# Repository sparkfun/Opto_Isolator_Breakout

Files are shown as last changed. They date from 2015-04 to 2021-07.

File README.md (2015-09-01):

SparkFun Opto-isolator Breakout 
===============================

SparkFun Opto-isolator Breakout

[*SparkFun Opto-isolator Breakout  (BOB-09118)*](https://www.sparkfun.com/products/9118)

This is a board designed for opto-isolation. 
This board is helpful for connecting digital systems (like a 5V microcontroller) to a high-voltage or noisy system. 
This board electrically isolates a controller from the high-power system by use of an opto-isolator IC.

Repository Contents
-------------------

* **/Hardware** - Eagle design files (.brd, .sch)
* **/Production** - Production panel files (.brd)

Documentation
--------------
* **[SparkFun Fritzing repo](https://github.com/sparkfun/Fritzing_Parts)** - Fritzing diagrams for SparkFun products.
* **[SparkFun 3D Model repo](https://github.com/sparkfun/3D_Models)** - 3D models of SparkFun products. 

License Information
-------------------

This product is _**open source**_! 

Please review the LICENSE.md file for license information. 

If you have any questions or concerns on licensing, please contact techsupport@sparkfun.com.

Distributed as-is; no warranty is given.

- Your friends at SparkFun.

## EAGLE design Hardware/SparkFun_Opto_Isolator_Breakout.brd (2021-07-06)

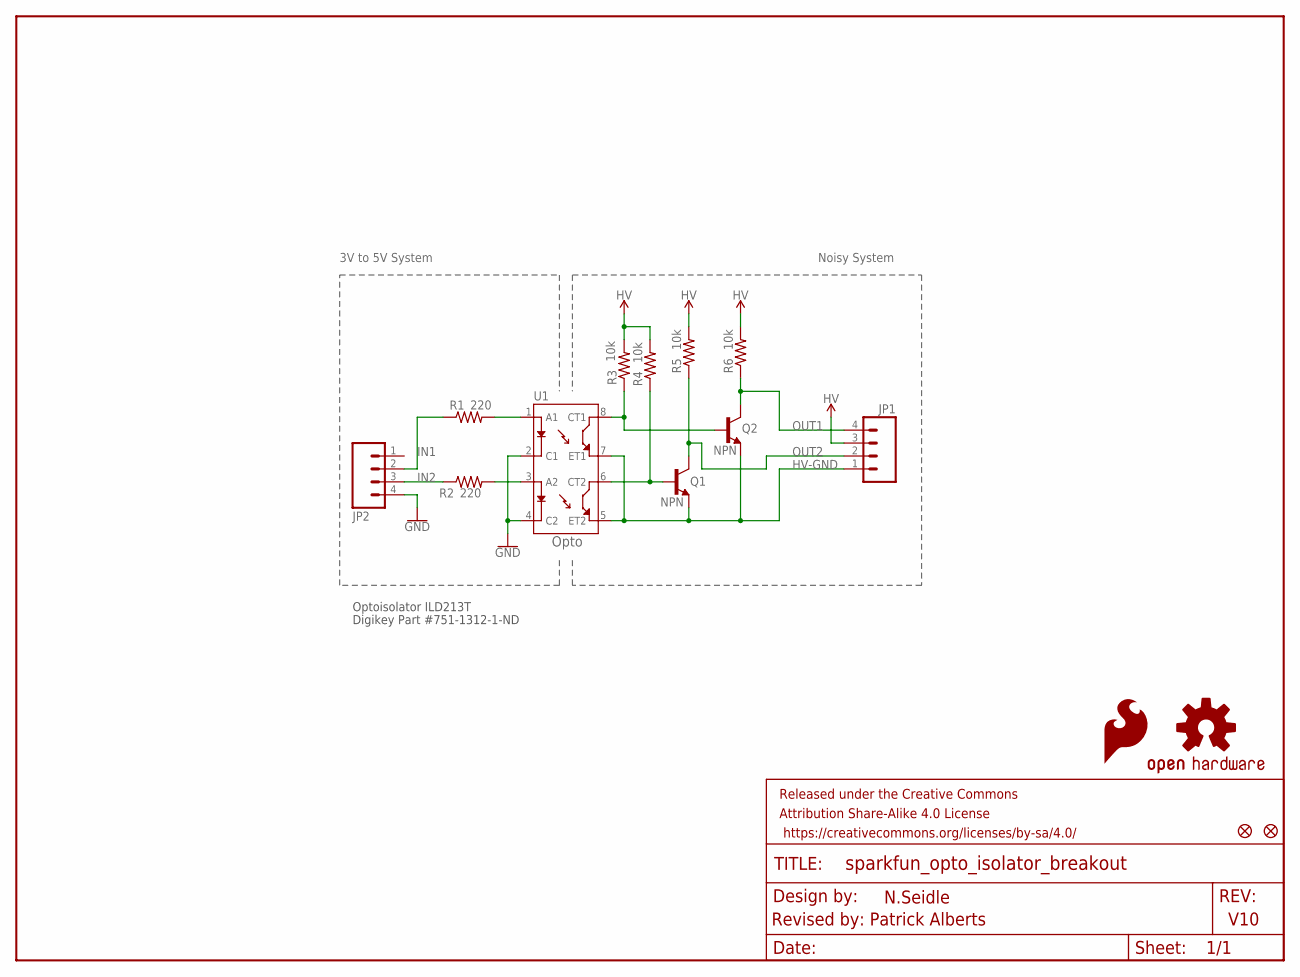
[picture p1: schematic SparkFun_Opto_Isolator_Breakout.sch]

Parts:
FRAME1: FRAME-LETTER; CREATIVE_COMMONS
JP1, JP2: M04PTH; 1X04
LOGO1: OSHW-LOGOS; OSHW-LOGO-S
LOGO2: SFE_LOGO_FLAME.1_INCH; SFE_LOGO_FLAME_.1
Q1, Q2: NPN; SOT23-3
R1, R2: 220; 0603
R3, R4, R5, R6: 10k; 0603
U1: ILD213T-IDL213T; SO08
U$2, U$3: FIDUCIALUFIDUCIAL; MICRO-FIDUCIAL

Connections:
GND: JP2.4, U1.2 (C1), U1.4 (C2)
HV-GND: JP1.1, Q1.2 (E), Q2.2 (E), U1.5 (ET2), U1.7 (ET1)
IN1: JP2.2, R1.1
IN2: JP2.3, R2.1
unnamed: R1.2, U1.1 (A1)
unnamed: R2.2, U1.3 (A2)
OUT1: JP1.4, Q2.3 (C), R6.1
OUT1N: Q2.1 (B), R3.1, U1.8 (CT1)
OUT2: JP1.2, Q1.3 (C), R5.1
OUT2N: Q1.1 (B), R4.1, U1.6 (CT2)
VCC: JP1.3, R3.2, R4.2, R5.2, R6.2

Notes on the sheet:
Optoisolator ILD213T
Digikey Part #751-1312-1-ND
3V to 5V System
Noisy System
V10
Revised by: Patrick Alberts
N.Seidle
Opto

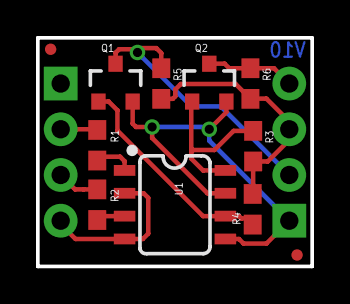
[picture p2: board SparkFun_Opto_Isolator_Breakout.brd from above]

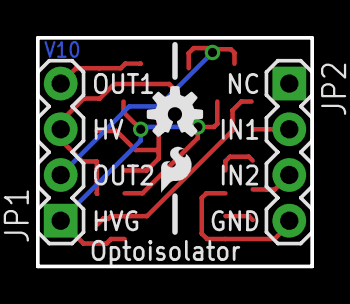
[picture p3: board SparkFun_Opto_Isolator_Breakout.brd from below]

Board: 2 copper layers, 15.2 x 12.7 mm, 16 parts (4 on the bottom side), 11 nets.

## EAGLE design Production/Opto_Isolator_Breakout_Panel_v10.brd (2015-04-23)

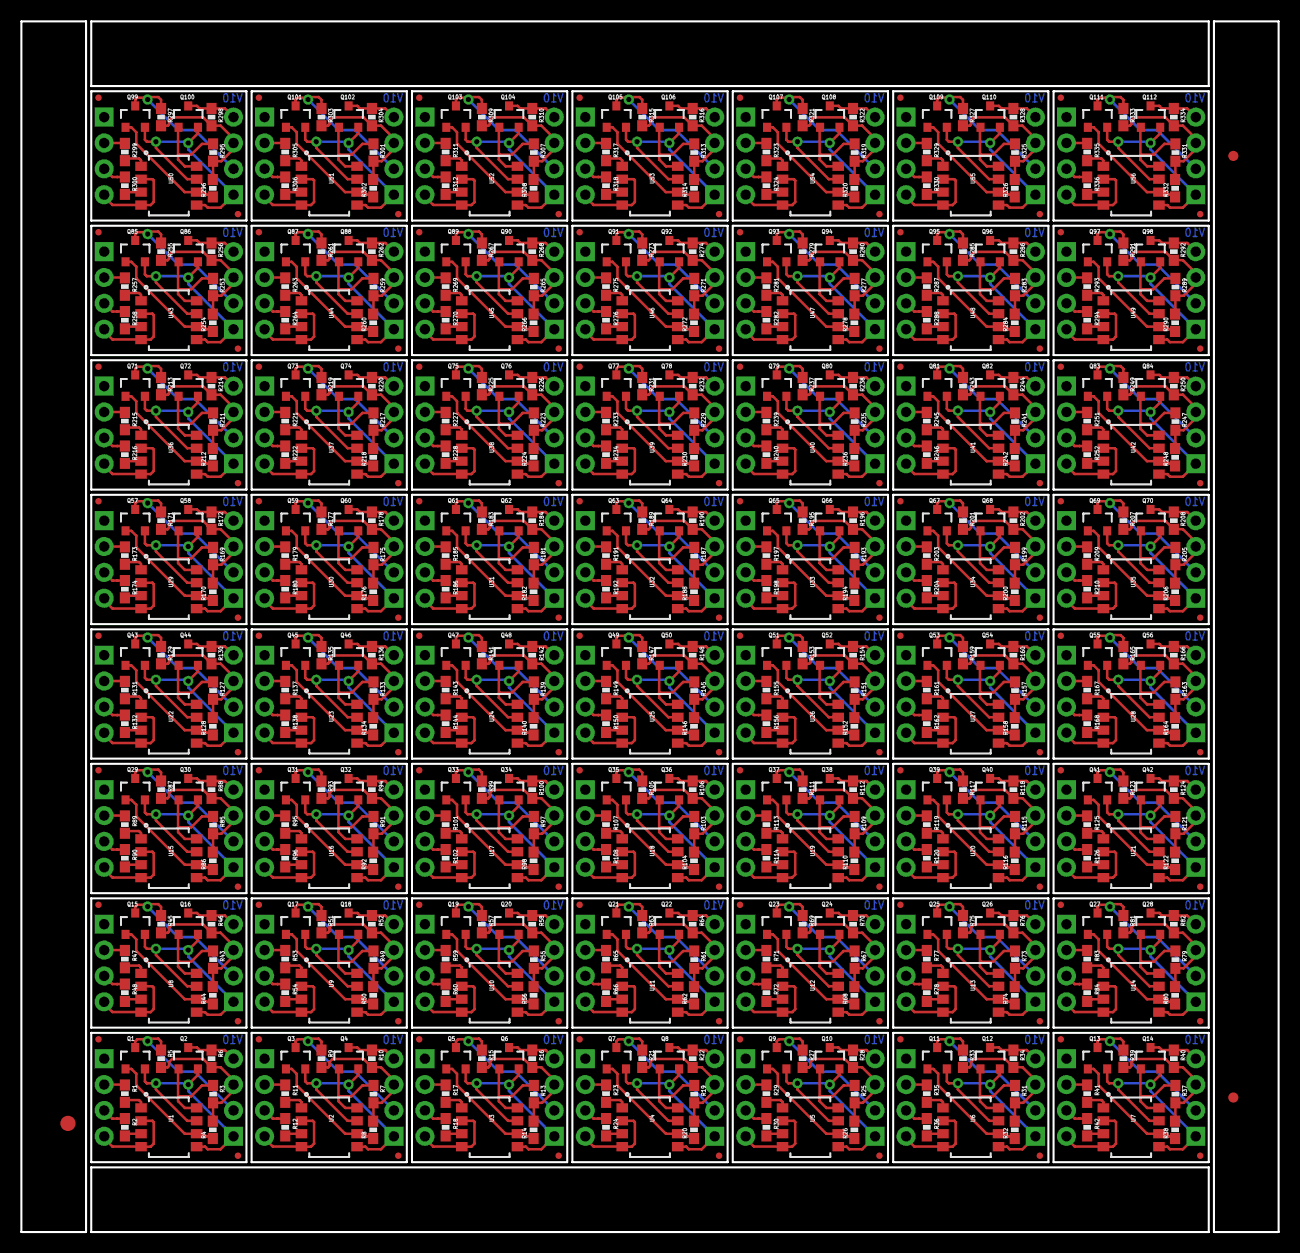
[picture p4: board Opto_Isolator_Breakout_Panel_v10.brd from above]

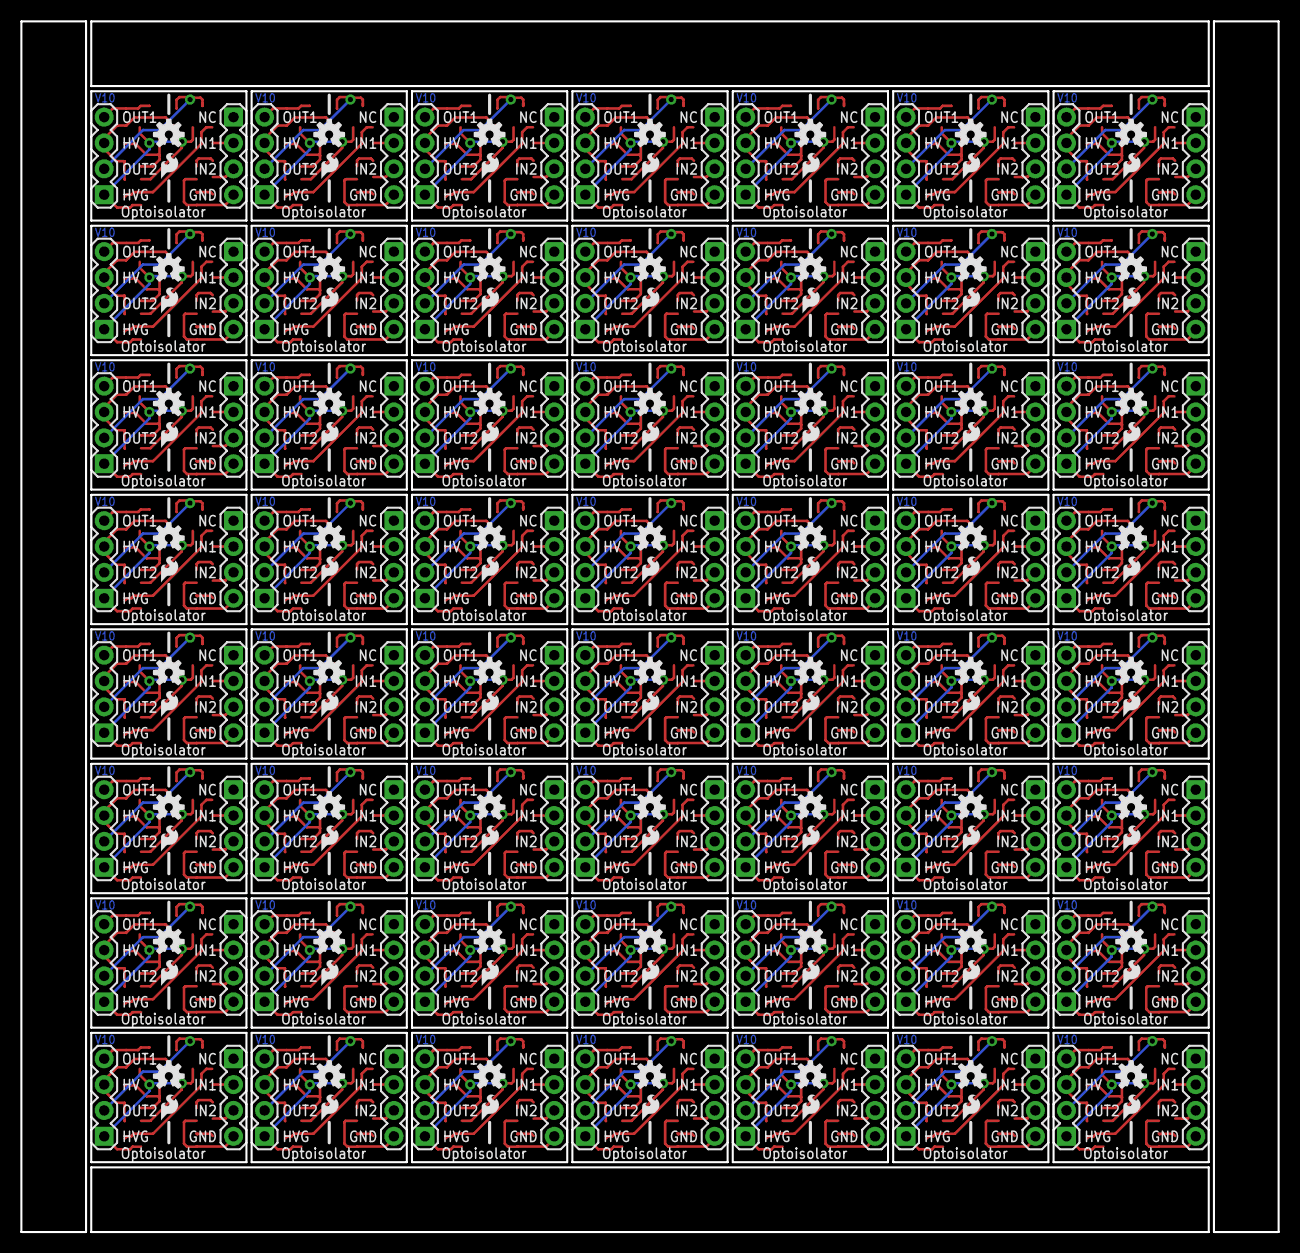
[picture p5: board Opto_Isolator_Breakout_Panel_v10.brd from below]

Board: 2 copper layers, 123.4 x 118.9 mm, 843 parts (224 on the bottom side), 616 nets.

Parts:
E$1: FIDUCIAL-1.5X3
E$4, E$5: FIDUCIAL-1X2
JP1, JP2, JP3, JP4, JP5, JP6, JP7, JP8, JP9, JP10, JP11, JP12, JP13, JP14, JP15, JP16, JP17, JP18, JP19, JP20, JP21, JP22, JP23, JP24, JP25, JP26, JP27, JP28, JP29, JP30, JP31, JP32, JP33, JP34, JP35, JP36, JP37, JP38, JP39, JP40, JP41, JP42, JP43, JP44, JP45, JP46, JP47, JP48, JP49, JP50, JP51, JP52, JP53, JP54, JP55, JP56, JP57, JP58, JP59, JP60, JP61, JP62, JP63, JP64, JP65, JP66, JP67, JP68, JP69, JP70, JP71, JP72, JP73, JP74, JP75, JP76, JP77, JP78, JP79, JP80, JP81, JP82, JP83, JP84, JP85, JP86, JP87, JP88, JP89, JP90, JP91, JP92, JP93, JP94, JP95, JP96, JP97, JP98, JP99, JP100, JP101, JP102, JP103, JP104, JP105, JP106, JP107, JP108, JP109, JP110, JP111, JP112: 1X04
LOGO1, LOGO4, LOGO6, LOGO8, LOGO10, LOGO12, LOGO14, LOGO16, LOGO18, LOGO20, LOGO22, LOGO24, LOGO26, LOGO28, LOGO30, LOGO32, LOGO34, LOGO36, LOGO38, LOGO40, LOGO42, LOGO44, LOGO46, LOGO48, LOGO50, LOGO52, LOGO54, LOGO56, LOGO58, LOGO60, LOGO62, LOGO64, LOGO66, LOGO68, LOGO70, LOGO72, LOGO74, LOGO76, LOGO78, LOGO80, LOGO82, LOGO84, LOGO86, LOGO88, LOGO90, LOGO92, LOGO94, LOGO96, LOGO98, LOGO100, LOGO102, LOGO104, LOGO106, LOGO108, LOGO110, LOGO112: OSHW-LOGOS; OSHW-LOGO-S
LOGO2, LOGO3, LOGO5, LOGO7, LOGO9, LOGO11, LOGO13, LOGO15, LOGO17, LOGO19, LOGO21, LOGO23, LOGO25, LOGO27, LOGO29, LOGO31, LOGO33, LOGO35, LOGO37, LOGO39, LOGO41, LOGO43, LOGO45, LOGO47, LOGO49, LOGO51, LOGO53, LOGO55, LOGO57, LOGO59, LOGO61, LOGO63, LOGO65, LOGO67, LOGO69, LOGO71, LOGO73, LOGO75, LOGO77, LOGO79, LOGO81, LOGO83, LOGO85, LOGO87, LOGO89, LOGO91, LOGO93, LOGO95, LOGO97, LOGO99, LOGO101, LOGO103, LOGO105, LOGO107, LOGO109, LOGO111: SFE_LOGO_FLAME.1_INCH; SFE_LOGO_FLAME_.1
Q1, Q2, Q3, Q4, Q5, Q6, Q7, Q8, Q9, Q10, Q11, Q12, Q13, Q14, Q15, Q16, Q17, Q18, Q19, Q20, Q21, Q22, Q23, Q24, Q25, Q26, Q27, Q28, Q29, Q30, Q31, Q32, Q33, Q34, Q35, Q36, Q37, Q38, Q39, Q40, Q41, Q42, Q43, Q44, Q45, Q46, Q47, Q48, Q49, Q50, Q51, Q52, Q53, Q54, Q55, Q56, Q57, Q58, Q59, Q60, Q61, Q62, Q63, Q64, Q65, Q66, Q67, Q68, Q69, Q70, Q71, Q72, Q73, Q74, Q75, Q76, Q77, Q78, Q79, Q80, Q81, Q82, Q83, Q84, Q85, Q86, Q87, Q88, Q89, Q90, Q91, Q92, Q93, Q94, Q95, Q96, Q97, Q98, Q99, Q100, Q101, Q102, Q103, Q104, Q105, Q106, Q107, Q108, Q109, Q110, Q111, Q112: NPN; SOT23-3
R1, R2, R11, R12, R17, R18, R23, R24, R29, R30, R35, R36, R41, R42, R47, R48, R53, R54, R59, R60, R65, R66, R71, R72, R77, R78, R83, R84, R89, R90, R95, R96, R101, R102, R107, R108, R113, R114, R119, R120, R125, R126, R131, R132, R137, R138, R143, R144, R149, R150, R155, R156, R161, R162, R167, R168, R173, R174, R179, R180, R185, R186, R191, R192, R197, R198, R203, R204, R209, R210, R215, R216, R221, R222, R227, R228, R233, R234, R239, R240, R245, R246, R251, R252, R257, R258, R263, R264, R269, R270, R275, R276, R281, R282, R287, R288, R293, R294, R299, R300, R305, R306, R311, R312, R317, R318, R323, R324, R329, R330, R335, R336: 220; 0603-RES
R3, R4, R5, R6, R7, R8, R9, R10, R13, R14, R15, R16, R19, R20, R21, R22, R25, R26, R27, R28, R31, R32, R33, R34, R37, R38, R39, R40, R43, R44, R45, R46, R49, R50, R51, R52, R55, R56, R57, R58, R61, R62, R63, R64, R67, R68, R69, R70, R73, R74, R75, R76, R79, R80, R81, R82, R85, R86, R87, R88, R91, R92, R93, R94, R97, R98, R99, R100, R103, R104, R105, R106, R109, R110, R111, R112, R115, R116, R117, R118, R121, R122, R123, R124, R127, R128, R129, R130, R133, R134, R135, R136, R139, R140, R141, R142, R145, R146, R147, R148, R151, R152, R153, R154, R157, R158, R159, R160, R163, R164, R165, R166, R169, R170, R171, R172, R175, R176, R177, R178, R181, R182, R183, R184, R187, R188, R189, R190, R193, R194, R195, R196, R199, R200, R201, R202, R205, R206, R207, R208, R211, R212, R213, R214, R217, R218, R219, R220, R223, R224, R225, R226, R229, R230, R231, R232, R235, R236, R237, R238, R241, R242, R243, R244, R247, R248, R249, R250, R253, R254, R255, R256, R259, R260, R261, R262, R265, R266, R267, R268, R271, R272, R273, R274, R277, R278, R279, R280, R283, R284, R285, R286, R289, R290, R291, R292, R295, R296, R297, R298, R301, R302, R303, R304, R307, R308, R309, R310, R313, R314, R315, R316, R319, R320, R321, R322, R325, R326, R327, R328, R331, R332, R333, R334: 10K; 0603-RES
U1, U2, U3, U4, U5, U6, U7, U8, U9, U10, U11, U12, U13, U14, U15, U16, U17, U18, U19, U20, U21, U22, U23, U24, U25, U26, U27, U28, U29, U30, U31, U32, U33, U34, U35, U36, U37, U38, U39, U40, U41, U42, U43, U44, U45, U46, U47, U48, U49, U50, U51, U52, U53, U54, U55, U56: OPTOISOLATOR-2SOIC8; SO08-2
U$1, U$2, U$3, U$4, U$5, U$6, U$7, U$8, U$9, U$10, U$11, U$12, U$13, U$14, U$15, U$16, U$17, U$18, U$19, U$20, U$21, U$22, U$23, U$24, U$25, U$26, U$27, U$28, U$29, U$30, U$31, U$32, U$33, U$34, U$35, U$36, U$37, U$38, U$39, U$40, U$41, U$42, U$43, U$44, U$45, U$46, U$47, U$48, U$49, U$50, U$51, U$52, U$53, U$54, U$55, U$56, U$57, U$58, U$59, U$60, U$61, U$62, U$63, U$64, U$65, U$66, U$67, U$68, U$69, U$70, U$71, U$72, U$73, U$74, U$75, U$76, U$77, U$78, U$79, U$80, U$81, U$82, U$83, U$84, U$85, U$86, U$87, U$88, U$89, U$90, U$91, U$92, U$93, U$94, U$95, U$96, U$97, U$98, U$99, U$100, U$101, U$102, U$103, U$104, U$105, U$106, U$107, U$108, U$109, U$110, U$111, U$112: FIDUCIALUFIDUCIAL; MICRO-FIDUCIAL

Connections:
GND: JP2.4, U1.2, U1.4
GND1: JP4.4, U2.2, U2.4
GND2: JP6.4, U3.2, U3.4
GND3: JP8.4, U4.2, U4.4
GND4: JP10.4, U5.2, U5.4
GND5: JP12.4, U6.2, U6.4
GND6: JP14.4, U7.2, U7.4
GND7: JP16.4, U8.2, U8.4
GND8: JP18.4, U9.2, U9.4
GND9: JP20.4, U10.2, U10.4
GND10: JP22.4, U11.2, U11.4
GND11: JP24.4, U12.2, U12.4
GND12: JP26.4, U13.2, U13.4
GND13: JP28.4, U14.2, U14.4
GND14: JP30.4, U15.2, U15.4
GND15: JP32.4, U16.2, U16.4
GND16: JP34.4, U17.2, U17.4
GND17: JP36.4, U18.2, U18.4
GND18: JP38.4, U19.2, U19.4
GND19: JP40.4, U20.2, U20.4
GND20: JP42.4, U21.2, U21.4
GND21: JP44.4, U22.2, U22.4
GND22: JP46.4, U23.2, U23.4
GND23: JP48.4, U24.2, U24.4
GND24: JP50.4, U25.2, U25.4
GND25: JP52.4, U26.2, U26.4
GND26: JP54.4, U27.2, U27.4
GND27: JP56.4, U28.2, U28.4
GND28: JP58.4, U29.2, U29.4
GND29: JP60.4, U30.2, U30.4
GND30: JP62.4, U31.2, U31.4
GND31: JP64.4, U32.2, U32.4
GND32: JP66.4, U33.2, U33.4
GND33: JP68.4, U34.2, U34.4
GND34: JP70.4, U35.2, U35.4
GND35: JP72.4, U36.2, U36.4
GND36: JP74.4, U37.2, U37.4
GND37: JP76.4, U38.2, U38.4
GND38: JP78.4, U39.2, U39.4
GND39: JP80.4, U40.2, U40.4
GND40: JP82.4, U41.2, U41.4
GND41: JP84.4, U42.2, U42.4
GND42: JP86.4, U43.2, U43.4
GND43: JP88.4, U44.2, U44.4
GND44: JP90.4, U45.2, U45.4
GND45: JP92.4, U46.2, U46.4
GND46: JP94.4, U47.2, U47.4
GND47: JP96.4, U48.2, U48.4
GND48: JP98.4, U49.2, U49.4
GND49: JP100.4, U50.2, U50.4
GND50: JP102.4, U51.2, U51.4
GND51: JP104.4, U52.2, U52.4
GND52: JP106.4, U53.2, U53.4
GND53: JP108.4, U54.2, U54.4
GND54: JP110.4, U55.2, U55.4
GND55: JP112.4, U56.2, U56.4
HV-GND: JP1.1, Q1.2, Q2.2, U1.5, U1.7
HV-GND1: JP3.1, Q3.2, Q4.2, U2.5, U2.7
HV-GND2: JP5.1, Q5.2, Q6.2, U3.5, U3.7
HV-GND3: JP7.1, Q7.2, Q8.2, U4.5, U4.7
HV-GND4: JP9.1, Q9.2, Q10.2, U5.5, U5.7
HV-GND5: JP11.1, Q11.2, Q12.2, U6.5, U6.7
HV-GND6: JP13.1, Q13.2, Q14.2, U7.5, U7.7
HV-GND7: JP15.1, Q15.2, Q16.2, U8.5, U8.7
HV-GND8: JP17.1, Q17.2, Q18.2, U9.5, U9.7
HV-GND9: JP19.1, Q19.2, Q20.2, U10.5, U10.7
HV-GND10: JP21.1, Q21.2, Q22.2, U11.5, U11.7
HV-GND11: JP23.1, Q23.2, Q24.2, U12.5, U12.7
HV-GND12: JP25.1, Q25.2, Q26.2, U13.5, U13.7
HV-GND13: JP27.1, Q27.2, Q28.2, U14.5, U14.7
HV-GND14: JP29.1, Q29.2, Q30.2, U15.5, U15.7
HV-GND15: JP31.1, Q31.2, Q32.2, U16.5, U16.7
HV-GND16: JP33.1, Q33.2, Q34.2, U17.5, U17.7
HV-GND17: JP35.1, Q35.2, Q36.2, U18.5, U18.7
HV-GND18: JP37.1, Q37.2, Q38.2, U19.5, U19.7
HV-GND19: JP39.1, Q39.2, Q40.2, U20.5, U20.7
HV-GND20: JP41.1, Q41.2, Q42.2, U21.5, U21.7
HV-GND21: JP43.1, Q43.2, Q44.2, U22.5, U22.7
HV-GND22: JP45.1, Q45.2, Q46.2, U23.5, U23.7
HV-GND23: JP47.1, Q47.2, Q48.2, U24.5, U24.7
HV-GND24: JP49.1, Q49.2, Q50.2, U25.5, U25.7
HV-GND25: JP51.1, Q51.2, Q52.2, U26.5, U26.7
HV-GND26: JP53.1, Q53.2, Q54.2, U27.5, U27.7
HV-GND27: JP55.1, Q55.2, Q56.2, U28.5, U28.7
HV-GND28: JP57.1, Q57.2, Q58.2, U29.5, U29.7
HV-GND29: JP59.1, Q59.2, Q60.2, U30.5, U30.7
HV-GND30: JP61.1, Q61.2, Q62.2, U31.5, U31.7
HV-GND31: JP63.1, Q63.2, Q64.2, U32.5, U32.7
HV-GND32: JP65.1, Q65.2, Q66.2, U33.5, U33.7
HV-GND33: JP67.1, Q67.2, Q68.2, U34.5, U34.7
HV-GND34: JP69.1, Q69.2, Q70.2, U35.5, U35.7
HV-GND35: JP71.1, Q71.2, Q72.2, U36.5, U36.7
HV-GND36: JP73.1, Q73.2, Q74.2, U37.5, U37.7
HV-GND37: JP75.1, Q75.2, Q76.2, U38.5, U38.7
HV-GND38: JP77.1, Q77.2, Q78.2, U39.5, U39.7
HV-GND39: JP79.1, Q79.2, Q80.2, U40.5, U40.7
HV-GND40: JP81.1, Q81.2, Q82.2, U41.5, U41.7
HV-GND41: JP83.1, Q83.2, Q84.2, U42.5, U42.7
HV-GND42: JP85.1, Q85.2, Q86.2, U43.5, U43.7
HV-GND43: JP87.1, Q87.2, Q88.2, U44.5, U44.7
HV-GND44: JP89.1, Q89.2, Q90.2, U45.5, U45.7
HV-GND45: JP91.1, Q91.2, Q92.2, U46.5, U46.7
HV-GND46: JP93.1, Q93.2, Q94.2, U47.5, U47.7
HV-GND47: JP95.1, Q95.2, Q96.2, U48.5, U48.7
HV-GND48: JP97.1, Q97.2, Q98.2, U49.5, U49.7
HV-GND49: JP99.1, Q99.2, Q100.2, U50.5, U50.7
HV-GND50: JP101.1, Q101.2, Q102.2, U51.5, U51.7
HV-GND51: JP103.1, Q103.2, Q104.2, U52.5, U52.7
HV-GND52: JP105.1, Q105.2, Q106.2, U53.5, U53.7
HV-GND53: JP107.1, Q107.2, Q108.2, U54.5, U54.7
HV-GND54: JP109.1, Q109.2, Q110.2, U55.5, U55.7
HV-GND55: JP111.1, Q111.2, Q112.2, U56.5, U56.7
IN1: JP2.2, R1.1
IN2: JP2.3, R2.1
IN3: JP4.3, R12.1
IN4: JP4.2, R11.1
IN5: JP6.3, R18.1
IN6: JP6.2, R17.1
IN7: JP8.3, R24.1
IN8: JP8.2, R23.1
IN9: JP10.3, R30.1
IN10: JP10.2, R29.1
IN11: JP12.3, R36.1
IN12: JP12.2, R35.1
IN13: JP14.3, R42.1
IN14: JP14.2, R41.1
IN15: JP16.3, R48.1
IN16: JP16.2, R47.1
IN17: JP18.3, R54.1
IN18: JP18.2, R53.1
IN19: JP20.3, R60.1
IN20: JP20.2, R59.1
IN21: JP22.3, R66.1
IN22: JP22.2, R65.1
IN23: JP24.3, R72.1
IN24: JP24.2, R71.1
IN25: JP26.3, R78.1
IN26: JP26.2, R77.1
IN27: JP28.3, R84.1
IN28: JP28.2, R83.1
IN29: JP30.3, R90.1
IN30: JP30.2, R89.1
IN31: JP32.3, R96.1
IN32: JP32.2, R95.1
IN33: JP34.3, R102.1
IN34: JP34.2, R101.1
IN35: JP36.3, R108.1
IN36: JP36.2, R107.1
IN37: JP38.3, R114.1
IN38: JP38.2, R113.1
IN39: JP40.3, R120.1
IN40: JP40.2, R119.1
IN41: JP42.3, R126.1
IN42: JP42.2, R125.1
IN43: JP44.3, R132.1
IN44: JP44.2, R131.1
IN45: JP46.3, R138.1
IN46: JP46.2, R137.1
IN47: JP48.3, R144.1
IN48: JP48.2, R143.1
IN49: JP50.3, R150.1
IN50: JP50.2, R149.1
IN51: JP52.3, R156.1
IN52: JP52.2, R155.1
IN53: JP54.3, R162.1
IN54: JP54.2, R161.1
IN55: JP56.3, R168.1
IN56: JP56.2, R167.1
IN57: JP58.3, R174.1
IN58: JP58.2, R173.1
IN59: JP60.3, R180.1
IN60: JP60.2, R179.1
IN61: JP62.3, R186.1
IN62: JP62.2, R185.1
IN63: JP64.3, R192.1
IN64: JP64.2, R191.1
IN65: JP66.3, R198.1
IN66: JP66.2, R197.1
IN67: JP68.3, R204.1
IN68: JP68.2, R203.1
IN69: JP70.3, R210.1
IN70: JP70.2, R209.1
IN71: JP72.3, R216.1
IN72: JP72.2, R215.1
IN73: JP74.3, R222.1
IN74: JP74.2, R221.1
IN75: JP76.3, R228.1
IN76: JP76.2, R227.1
IN77: JP78.3, R234.1
IN78: JP78.2, R233.1
IN79: JP80.3, R240.1
IN80: JP80.2, R239.1
IN81: JP82.3, R246.1
IN82: JP82.2, R245.1
IN83: JP84.3, R252.1
IN84: JP84.2, R251.1
IN85: JP86.3, R258.1
IN86: JP86.2, R257.1
IN87: JP88.3, R264.1
IN88: JP88.2, R263.1
IN89: JP90.3, R270.1
IN90: JP90.2, R269.1
IN91: JP92.3, R276.1
IN92: JP92.2, R275.1
IN93: JP94.3, R282.1
IN94: JP94.2, R281.1
IN95: JP96.3, R288.1
IN96: JP96.2, R287.1
IN97: JP98.3, R294.1
IN98: JP98.2, R293.1
IN99: JP100.3, R300.1
IN100: JP100.2, R299.1
IN101: JP102.3, R306.1
IN102: JP102.2, R305.1
IN103: JP104.3, R312.1
IN104: JP104.2, R311.1
IN105: JP106.3, R318.1
IN106: JP106.2, R317.1
IN107: JP108.3, R324.1
IN108: JP108.2, R323.1
IN109: JP110.3, R330.1
IN110: JP110.2, R329.1
IN111: JP112.3, R336.1
IN112: JP112.2, R335.1
unnamed: R1.2, U1.1
unnamed: R2.2, U1.3
unnamed: R11.2, U2.1
unnamed: R12.2, U2.3
unnamed: R17.2, U3.1
unnamed: R18.2, U3.3
unnamed: R23.2, U4.1
unnamed: R24.2, U4.3
unnamed: R29.2, U5.1
unnamed: R30.2, U5.3
unnamed: R35.2, U6.1
unnamed: R36.2, U6.3
unnamed: R41.2, U7.1
unnamed: R42.2, U7.3
unnamed: R47.2, U8.1
unnamed: R48.2, U8.3
unnamed: R53.2, U9.1
unnamed: R54.2, U9.3
unnamed: R59.2, U10.1
unnamed: R60.2, U10.3
unnamed: R65.2, U11.1
unnamed: R66.2, U11.3
unnamed: R71.2, U12.1
unnamed: R72.2, U12.3
unnamed: R77.2, U13.1
unnamed: R78.2, U13.3
unnamed: R83.2, U14.1
unnamed: R84.2, U14.3
unnamed: R89.2, U15.1
unnamed: R90.2, U15.3
unnamed: R95.2, U16.1
unnamed: R96.2, U16.3
unnamed: R101.2, U17.1
unnamed: R102.2, U17.3
unnamed: R107.2, U18.1
unnamed: R108.2, U18.3
unnamed: R113.2, U19.1
unnamed: R114.2, U19.3
unnamed: R119.2, U20.1
unnamed: R120.2, U20.3
unnamed: R125.2, U21.1
unnamed: R126.2, U21.3
unnamed: R131.2, U22.1
unnamed: R132.2, U22.3
unnamed: R137.2, U23.1
unnamed: R138.2, U23.3
unnamed: R143.2, U24.1
unnamed: R144.2, U24.3
unnamed: R149.2, U25.1
unnamed: R150.2, U25.3
unnamed: R155.2, U26.1
unnamed: R156.2, U26.3
unnamed: R161.2, U27.1
unnamed: R162.2, U27.3
unnamed: R167.2, U28.1
unnamed: R168.2, U28.3
unnamed: R173.2, U29.1
unnamed: R174.2, U29.3
unnamed: R179.2, U30.1
unnamed: R180.2, U30.3
unnamed: R185.2, U31.1
unnamed: R186.2, U31.3
unnamed: R191.2, U32.1
unnamed: R192.2, U32.3
unnamed: R197.2, U33.1
unnamed: R198.2, U33.3
unnamed: R203.2, U34.1
unnamed: R204.2, U34.3
unnamed: R209.2, U35.1
unnamed: R210.2, U35.3
unnamed: R215.2, U36.1
unnamed: R216.2, U36.3
unnamed: R221.2, U37.1
unnamed: R222.2, U37.3
unnamed: R227.2, U38.1
unnamed: R228.2, U38.3
unnamed: R233.2, U39.1
unnamed: R234.2, U39.3
unnamed: R239.2, U40.1
unnamed: R240.2, U40.3
unnamed: R245.2, U41.1
unnamed: R246.2, U41.3
unnamed: R251.2, U42.1
unnamed: R252.2, U42.3
unnamed: R257.2, U43.1
unnamed: R258.2, U43.3
unnamed: R263.2, U44.1
unnamed: R264.2, U44.3
unnamed: R269.2, U45.1
unnamed: R270.2, U45.3
unnamed: R275.2, U46.1
unnamed: R276.2, U46.3
unnamed: R281.2, U47.1
unnamed: R282.2, U47.3
unnamed: R287.2, U48.1
unnamed: R288.2, U48.3
unnamed: R293.2, U49.1
unnamed: R294.2, U49.3
unnamed: R299.2, U50.1
unnamed: R300.2, U50.3
unnamed: R305.2, U51.1
unnamed: R306.2, U51.3
unnamed: R311.2, U52.1
unnamed: R312.2, U52.3
unnamed: R317.2, U53.1
unnamed: R318.2, U53.3
unnamed: R323.2, U54.1
unnamed: R324.2, U54.3
unnamed: R329.2, U55.1
unnamed: R330.2, U55.3
unnamed: R335.2, U56.1
unnamed: R336.2, U56.3
OUT1: JP1.4, Q2.3, R6.1
OUT1N: Q2.1, R3.1, U1.8
OUT1N1: Q4.1, R7.1, U2.8
OUT1N2: Q6.1, R13.1, U3.8
OUT1N3: Q8.1, R19.1, U4.8
OUT1N4: Q10.1, R25.1, U5.8
OUT1N5: Q12.1, R31.1, U6.8
OUT1N6: Q14.1, R37.1, U7.8
OUT1N7: Q16.1, R43.1, U8.8
OUT1N8: Q18.1, R49.1, U9.8
OUT1N9: Q20.1, R55.1, U10.8
OUT1N10: Q22.1, R61.1, U11.8
OUT1N11: Q24.1, R67.1, U12.8
OUT1N12: Q26.1, R73.1, U13.8
OUT1N13: Q28.1, R79.1, U14.8
OUT1N14: Q30.1, R85.1, U15.8
OUT1N15: Q32.1, R91.1, U16.8
OUT1N16: Q34.1, R97.1, U17.8
OUT1N17: Q36.1, R103.1, U18.8
OUT1N18: Q38.1, R109.1, U19.8
OUT1N19: Q40.1, R115.1, U20.8
OUT1N20: Q42.1, R121.1, U21.8
OUT1N21: Q44.1, R127.1, U22.8
OUT1N22: Q46.1, R133.1, U23.8
OUT1N23: Q48.1, R139.1, U24.8
OUT1N24: Q50.1, R145.1, U25.8
OUT1N25: Q52.1, R151.1, U26.8
OUT1N26: Q54.1, R157.1, U27.8
OUT1N27: Q56.1, R163.1, U28.8
OUT1N28: Q58.1, R169.1, U29.8
OUT1N29: Q60.1, R175.1, U30.8
OUT1N30: Q62.1, R181.1, U31.8
OUT1N31: Q64.1, R187.1, U32.8
OUT1N32: Q66.1, R193.1, U33.8
OUT1N33: Q68.1, R199.1, U34.8
OUT1N34: Q70.1, R205.1, U35.8
OUT1N35: Q72.1, R211.1, U36.8
OUT1N36: Q74.1, R217.1, U37.8
OUT1N37: Q76.1, R223.1, U38.8
OUT1N38: Q78.1, R229.1, U39.8
OUT1N39: Q80.1, R235.1, U40.8
OUT1N40: Q82.1, R241.1, U41.8
OUT1N41: Q84.1, R247.1, U42.8
OUT1N42: Q86.1, R253.1, U43.8
OUT1N43: Q88.1, R259.1, U44.8
OUT1N44: Q90.1, R265.1, U45.8
OUT1N45: Q92.1, R271.1, U46.8
OUT1N46: Q94.1, R277.1, U47.8
OUT1N47: Q96.1, R283.1, U48.8
OUT1N48: Q98.1, R289.1, U49.8
OUT1N49: Q100.1, R295.1, U50.8
OUT1N50: Q102.1, R301.1, U51.8
OUT1N51: Q104.1, R307.1, U52.8
OUT1N52: Q106.1, R313.1, U53.8
OUT1N53: Q108.1, R319.1, U54.8
OUT1N54: Q110.1, R325.1, U55.8
OUT1N55: Q112.1, R331.1, U56.8
OUT2: JP1.2, Q1.3, R5.1
OUT2N: Q1.1, R4.1, U1.6
OUT2N1: Q3.1, R8.1, U2.6
OUT2N2: Q5.1, R14.1, U3.6
OUT2N3: Q7.1, R20.1, U4.6
OUT2N4: Q9.1, R26.1, U5.6
OUT2N5: Q11.1, R32.1, U6.6
OUT2N6: Q13.1, R38.1, U7.6
OUT2N7: Q15.1, R44.1, U8.6
OUT2N8: Q17.1, R50.1, U9.6
OUT2N9: Q19.1, R56.1, U10.6
OUT2N10: Q21.1, R62.1, U11.6
OUT2N11: Q23.1, R68.1, U12.6
OUT2N12: Q25.1, R74.1, U13.6
OUT2N13: Q27.1, R80.1, U14.6
OUT2N14: Q29.1, R86.1, U15.6
OUT2N15: Q31.1, R92.1, U16.6
OUT2N16: Q33.1, R98.1, U17.6
OUT2N17: Q35.1, R104.1, U18.6
OUT2N18: Q37.1, R110.1, U19.6
OUT2N19: Q39.1, R116.1, U20.6
OUT2N20: Q41.1, R122.1, U21.6
OUT2N21: Q43.1, R128.1, U22.6
OUT2N22: Q45.1, R134.1, U23.6
OUT2N23: Q47.1, R140.1, U24.6
OUT2N24: Q49.1, R146.1, U25.6
OUT2N25: Q51.1, R152.1, U26.6
OUT2N26: Q53.1, R158.1, U27.6
OUT2N27: Q55.1, R164.1, U28.6
OUT2N28: Q57.1, R170.1, U29.6
OUT2N29: Q59.1, R176.1, U30.6
OUT2N30: Q61.1, R182.1, U31.6
OUT2N31: Q63.1, R188.1, U32.6
OUT2N32: Q65.1, R194.1, U33.6
OUT2N33: Q67.1, R200.1, U34.6
OUT2N34: Q69.1, R206.1, U35.6
OUT2N35: Q71.1, R212.1, U36.6
OUT2N36: Q73.1, R218.1, U37.6
OUT2N37: Q75.1, R224.1, U38.6
OUT2N38: Q77.1, R230.1, U39.6
OUT2N39: Q79.1, R236.1, U40.6
OUT2N40: Q81.1, R242.1, U41.6
OUT2N41: Q83.1, R248.1, U42.6
OUT2N42: Q85.1, R254.1, U43.6
OUT2N43: Q87.1, R260.1, U44.6
OUT2N44: Q89.1, R266.1, U45.6
OUT2N45: Q91.1, R272.1, U46.6
OUT2N46: Q93.1, R278.1, U47.6
OUT2N47: Q95.1, R284.1, U48.6
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

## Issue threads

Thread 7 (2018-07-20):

MIDI In issue

jardous, 2018-07-20:
Hello, I have bought this breakout board and wanted to use if for MIDI input for my Arduino based project. Unfortunately it seems to not be working.

A little googling pointed me to https://www.sparkfun.com/products/9118, where I found a review comment:

"The 10k load resistors on the “output side” mean the switching time of the optocoupled transistors are close to 100 us, which means baud rates above 9600 will not work. This means the breakout is useless for a MIDI application (which is optoisolated transmission at 31250 baud serial). So good for isolation, not for fast signalling."

I would expect that to be mentioned in the description. That could save some headache...

nseidle, 2018-07-23:
Agreed. Thanks for the feedback and sorry for the headache! Request for description is in. Should be changed shortly.

Closed 2018-07-23.

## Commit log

2014-10-29 initial commit with brd/sch
    [Opto_Isolator_Breakout.brd, Opto_Isolator_Breakout.sch]
2014-10-29 0603, sch changes, re routes, oshw and headers
    Update all res/caps to 0603
    minor trace re routes
    oshw added and sch frame update to letter
    moved feducials to micro
    updated headers to have correct annual ring size
    [Opto_Isolator_Breakout.brd, Opto_Isolator_Breakout.sch]
2014-11-06 Changed Res Values / SCH cleanup
    changed r1 and r2 to 200K
    Added version # and eng to board/sch files
    [Opto_Isolator_Breakout.brd, Opto_Isolator_Breakout.sch]
2015-01-14 Computer change
    [Opto_Isolator_Breakout.brd]
2015-03-26 Added attributes for IC IDL213T
    [Opto_Isolator_Breakout.brd, Opto_Isolator_Breakout.sch]
2015-03-31 Fixed qc checklist issues.
    [Opto_Isolator_Breakout.brd, Opto_Isolator_Breakout.sch]
2015-03-31 Fixed final qc checklist items.
    [Opto_Isolator_Breakout.brd, Opto_Isolator_Breakout.sch]
2015-04-20 Fixed QC checklist issues
    Fixed version # in sch and brd
    added "all units in inches" in layer 47
    [Opto_Isolator_Breakout.brd, Opto_Isolator_Breakout.sch]
2015-04-23 created panel v10
    [Opto_Isolator_Breakout_Panel_v10.brd]
2015-09-01 Adding license and .git files, updating README with product info
    [Opto_Isolator_Breakout_Panel_v10.brd, SparkFun_Opto_Isolator_Breakout.brd, SparkFun_Opto_Isolator_Breakout.sch]
2021-07-06 Replace ILD213T with updated part
    [SparkFun_Opto_Isolator_Breakout.brd, SparkFun_Opto_Isolator_Breakout.sch]

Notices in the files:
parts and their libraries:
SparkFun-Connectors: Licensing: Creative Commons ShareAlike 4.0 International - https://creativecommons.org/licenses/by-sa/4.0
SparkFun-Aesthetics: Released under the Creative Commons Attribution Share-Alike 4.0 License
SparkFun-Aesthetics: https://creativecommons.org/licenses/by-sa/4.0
